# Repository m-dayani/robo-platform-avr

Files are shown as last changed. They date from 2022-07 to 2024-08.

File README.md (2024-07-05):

# ROBO Platform | AVR Controller

The AVR microcontroller board is a component of the [Robo Platform project](https://github.com/m-dayani/robo-platform), which provides general-purpose inputs and outputs for a cell phone controller. Both hardware schematics and software are available.

This project is based on the [Obdev V-USB Library](https://www.obdev.at/products/vusb/index.html).

## Hardware

The hardware was initially designed for the [ATMEL ATmega8](https://www.microchip.com/en-us/product/ATMEGA8) AVR microcontroller using the Cadsoft Eagle (now [Autodesk Eagle](https://www.autodesk.com/products/eagle/free-download)).
Schematics and PCB layouts are available for SMD and TH (Through hole) technologies.

## Software

Based on the V-USB library, the algorithm handles USB interactions with an Android device (the [Robo Platform Android App](https://github.com/m-dayani/robo-platform-android)) and produces the required signals and commands.

The program is written in the C programming language and developed, compiled, and tested in [ATMEL AVR Studio 6.1](https://www.microchip.com/en-us/tools-resources/archives/avr-sam-mcus).

## Usage

The instructions to use this project are the same as any other Obdev V-USB project:

- Prepare the development board
- Implement your logic, link the library, and compile
- Upload the .hex file to the microcontroller
- You should also install an appropriate driver to connect the board to a desktop computer. This step can be skipped for connections to Android devices (using an OTG cable, Android auto-detects the device).

You can learn more about it in [this step-by-step tutorial](https://codeandlife.com/2012/01/22/avr-attiny-usb-tutorial-part-1/).

_WARNING_: Be careful with fuse bits when flashing your microcontroller in Linux (using Makefile). It is recommended you do not use `program` or `fuse` targets with `make`. If you upload the wrong fuse bits, your device might not work again.

## Troubleshooting

In case the board does not respond to USB commands:

- Check the connections
- Make sure the program is compiled for the right microcontroller (e.g. Atmega32)
- Make sure the frequency is correct (12MHz) and fuse bits are programmed correctly

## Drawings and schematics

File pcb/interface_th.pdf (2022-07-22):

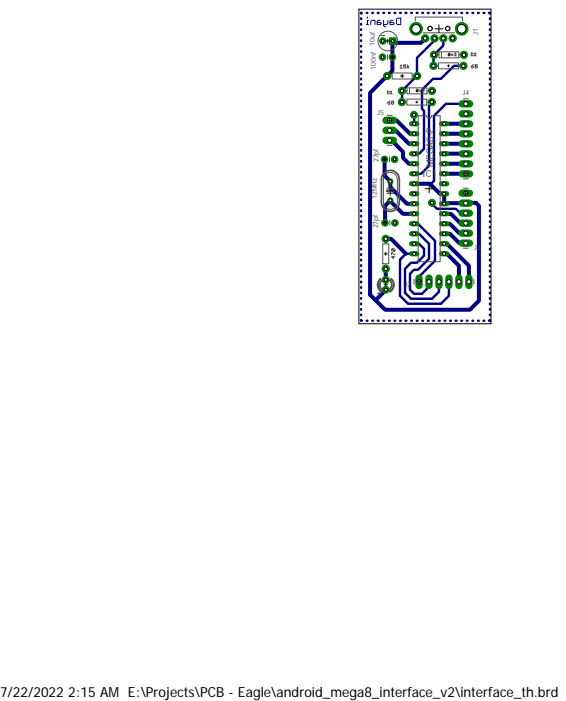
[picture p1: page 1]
MEGA8-P; 12MHz

7/22/2022 2:15 AM E:\Projects\PCB - Eagle\android_mega8_interface_v2\interface_th.brd

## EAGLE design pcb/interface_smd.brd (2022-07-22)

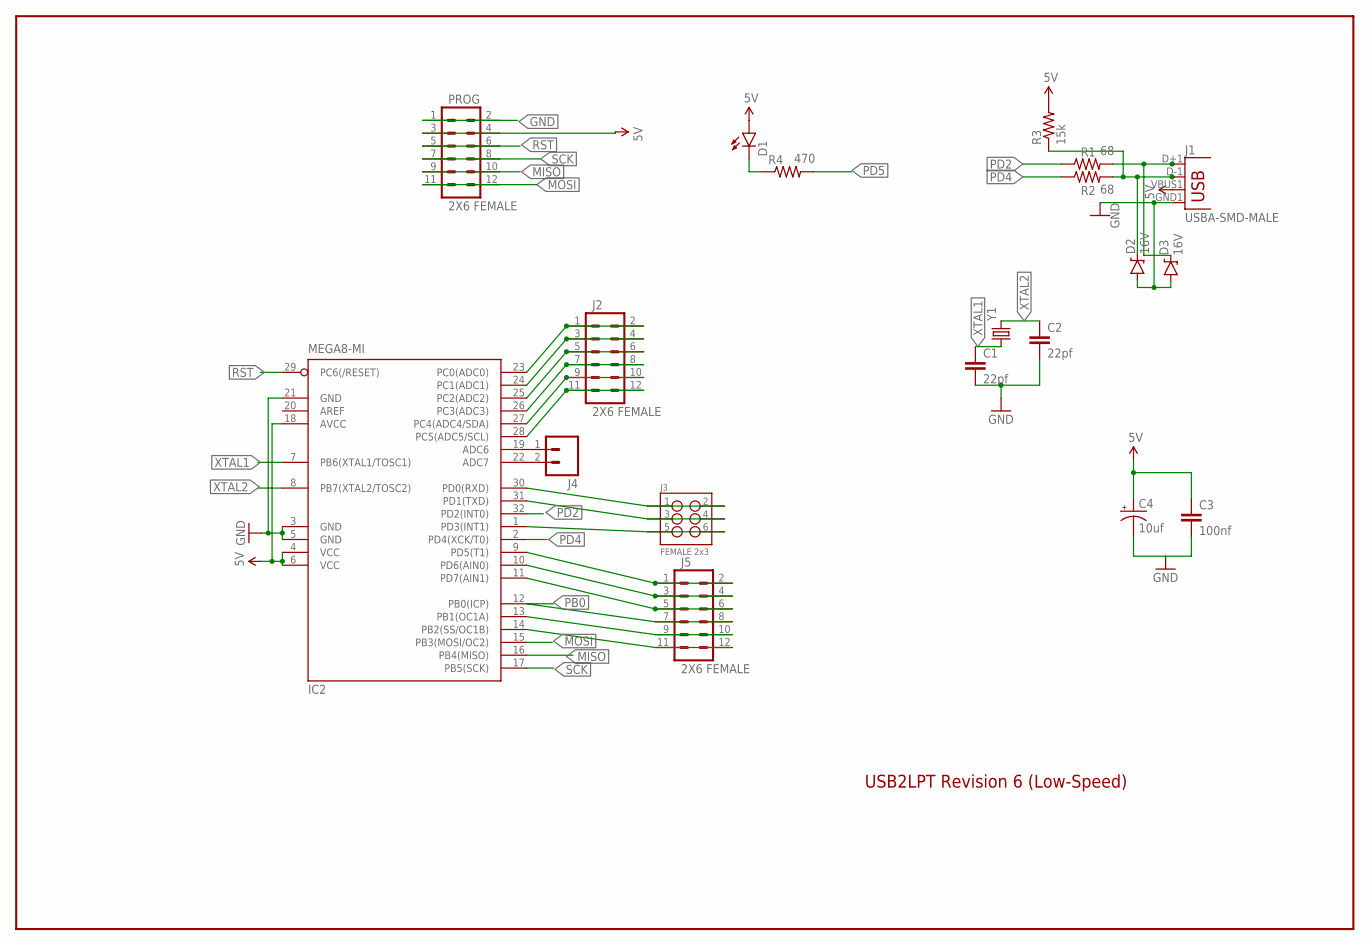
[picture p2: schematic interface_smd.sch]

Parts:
C1, C2: 22pf; 1206
C3: 100nf; 1206
C4: 10uf; EIA3216
D1: LED1206; LED-1206
D2, D3: 16V; SOD-123
IC2: MEGA8-MI; MLF32
J1: USBA-SMD-MALE; USB-A-SMT-MALE
J2, J5: 2X6 FEMALE; 2X6
J3: FEMALE 2x3; 2X3
J4: M02PTH; 1X02
PROG: 2X6 FEMALE; 2X6
R1, R2: 68; 1206
R3: 15k; 1206
R4: 470; 1206
Y1: CRYSTAL10.5X4.8; CRYSTAL-SMD-10.5X4.8-2PIN

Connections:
5V: C3.1, C4.A (+), D1.A, IC2.4 (VCC), IC2.6 (VCC), IC2.18 (AVCC), J1.VBUS1 (VBUS), PROG.3, PROG.4, R3.2
GND: C1.2, C2.2, C3.2, C4.C (-), D2.A, D3.A, IC2.3 (GND), IC2.5 (GND), IC2.21 (GND), J1.GND1 (GND), PROG.1, PROG.2
MISO: IC2.16 (PB4(MISO)), PROG.9, PROG.10
MOSI: IC2.15 (PB3(MOSI/OC2)), PROG.11, PROG.12
unnamed: D1.C, R4.1
unnamed: IC2.23 (PC0(ADC0)), J2.1, J2.2
unnamed: D3.C, J1.D+1 (D+), R1.2
unnamed: IC2.24 (PC1(ADC1)), J2.3, J2.4
unnamed: IC2.25 (PC2(ADC2)), J2.5, J2.6
unnamed: D2.C, J1.D-1 (D-), R2.2, R3.1
unnamed: IC2.26 (PC3(ADC3)), J2.7, J2.8
unnamed: IC2.27 (PC4(ADC4/SDA)), J2.9, J2.10
unnamed: IC2.28 (PC5(ADC5/SCL)), J2.11, J2.12
unnamed: IC2.19 (ADC6), J4.1
unnamed: IC2.22 (ADC7), J4.2
unnamed: IC2.30 (PD0(RXD)), J3.1, J3.2
unnamed: IC2.31 (PD1(TXD)), J3.3, J3.4
unnamed: IC2.1 (PD3(INT1)), J3.5, J3.6
unnamed: IC2.10 (PD6(AIN0)), J5.3, J5.4
unnamed: IC2.11 (PD7(AIN1)), J5.5, J5.6
unnamed: IC2.13 (PB1(OC1A)), J5.9, J5.10
unnamed: IC2.14 (PB2(SS/OC1B)), J5.11, J5.12
PB0: IC2.12 (PB0(ICP)), J5.7, J5.8
PD2: IC2.32 (PD2(INT0)), R1.1
PD4: IC2.2 (PD4(XCK/T0)), R2.1
PD5: IC2.9 (PD5(T1)), J5.1, J5.2, R4.2
RST: IC2.29 (PC6(/RESET)), PROG.5, PROG.6
SCK: IC2.17 (PB5(SCK)), PROG.7, PROG.8
XTAL1: C1.1, IC2.7 (PB6(XTAL1/TOSC1)), Y1.P$1 (1)
XTAL2: C2.1, IC2.8 (PB7(XTAL2/TOSC2)), Y1.P$2 (2)

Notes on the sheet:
USB2LPT Revision 6 (Low-Speed)

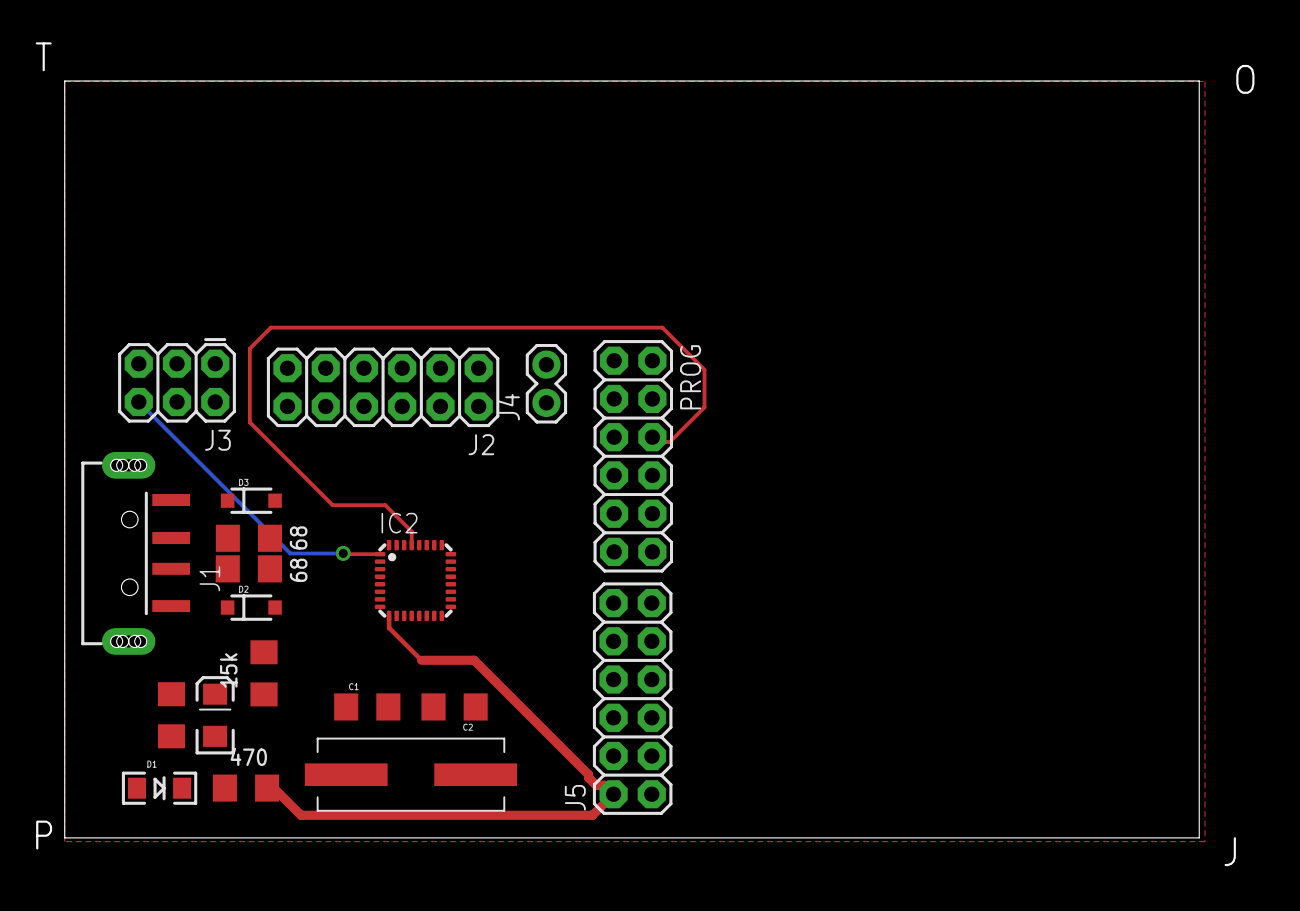
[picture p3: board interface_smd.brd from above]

Board: 2 copper layers, 75.4 x 50.3 mm, 19 parts (0 on the bottom side), 30 nets.

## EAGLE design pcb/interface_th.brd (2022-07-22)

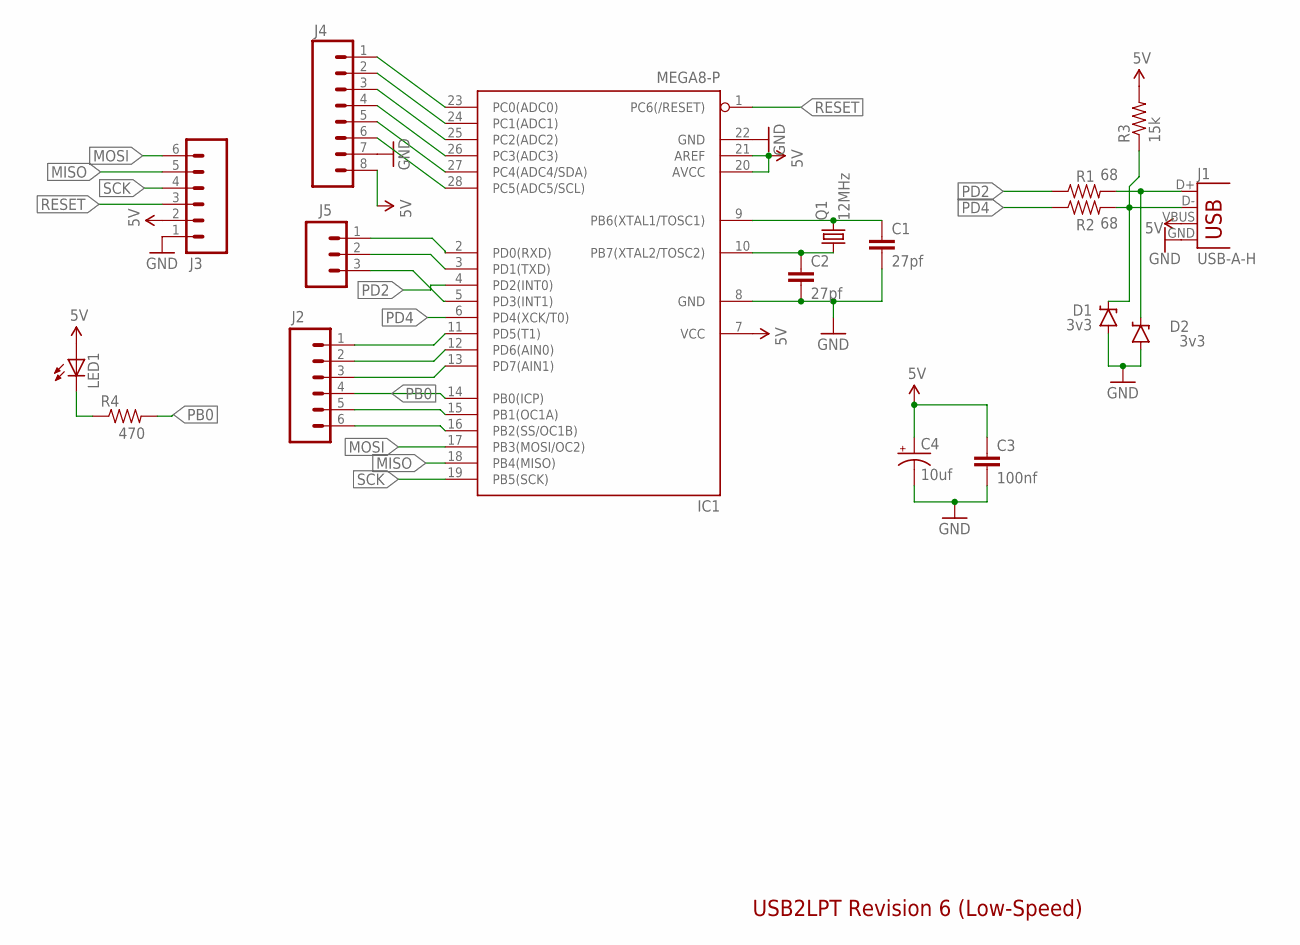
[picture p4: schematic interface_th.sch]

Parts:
C1, C2: 27pf; CAP-PTH-SMALL
C3: 100nf; CAP-PTH-SMALL
C4: 10uf; CPOL-RADIAL-10UF-25V
D1, D2: 3v3; DIODE-BZT52
IC1: MEGA8-P; DIL28-3
J1: USB-A-H
J2, J3: M06LONGPADS; 1X06_LONGPADS
J4: M08LONGPADS; 1X08_LONGPADS
J5: M03LONGPADS; 1X03_LONGPADS
LED1: LED3MM
Q1: 12MHz; HC49U-V
R1, R2: 68; AXIAL-0.3
R3: 15k; AXIAL-0.3
R4: 470; AXIAL-0.3

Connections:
5V: C3.1, C4.1 (+), IC1.7 (VCC), IC1.20 (AVCC), IC1.21 (AREF), J1.VBUS, J3.2, J4.8, LED1.A, R3.P$2 (2)
GND: C1.2, C2.2, C3.2, C4.2 (-), D1.A, D2.A, IC1.8 (GND), IC1.22 (GND), J1.GND, J3.1, J4.7
MISO: IC1.18 (PB4(MISO)), J3.5
MOSI: IC1.17 (PB3(MOSI/OC2)), J3.6
unnamed: LED1.K (C), R4.P$1 (1)
unnamed: IC1.11 (PD5(T1)), J2.1
unnamed: IC1.23 (PC0(ADC0)), J4.1
unnamed: C2.1, IC1.10 (PB7(XTAL2/TOSC2)), Q1.1
unnamed: C1.1, IC1.9 (PB6(XTAL1/TOSC1)), Q1.2
unnamed: D1.C, J1.D-, R2.P$2 (2), R3.P$1 (1)
unnamed: D2.C, J1.D+, R1.P$2 (2)
unnamed: IC1.24 (PC1(ADC1)), J4.2
unnamed: IC1.25 (PC2(ADC2)), J4.3
unnamed: IC1.26 (PC3(ADC3)), J4.4
unnamed: IC1.27 (PC4(ADC4/SDA)), J4.5
unnamed: IC1.28 (PC5(ADC5/SCL)), J4.6
unnamed: IC1.12 (PD6(AIN0)), J2.2
unnamed: IC1.13 (PD7(AIN1)), J2.3
unnamed: IC1.15 (PB1(OC1A)), J2.5
unnamed: IC1.16 (PB2(SS/OC1B)), J2.6
unnamed: IC1.2 (PD0(RXD)), J5.1
unnamed: IC1.3 (PD1(TXD)), J5.2
unnamed: IC1.5 (PD3(INT1)), J5.3
PB0: IC1.14 (PB0(ICP)), J2.4, R4.P$2 (2)
PD2: IC1.4 (PD2(INT0)), R1.P$1 (1)
PD4: IC1.6 (PD4(XCK/T0)), R2.P$1 (1)
RESET: IC1.1 (PC6(/RESET)), J3.3
SCK: IC1.19 (PB5(SCK)), J3.4

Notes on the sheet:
USB2LPT Revision 6 (Low-Speed)

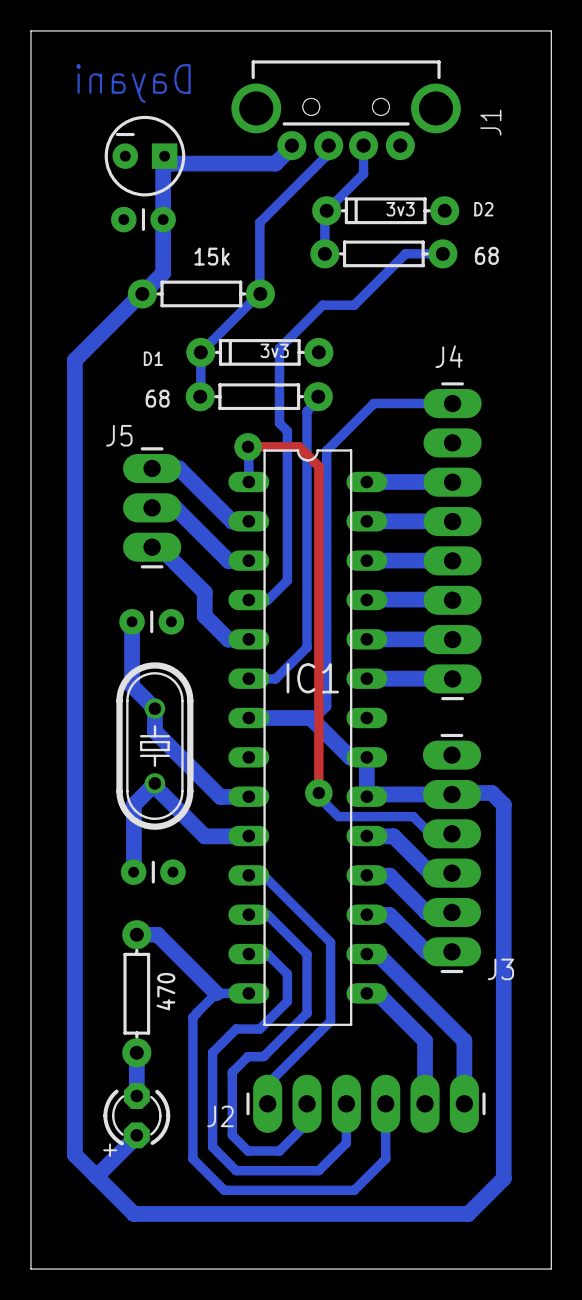
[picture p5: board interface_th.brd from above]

Board: 2 copper layers, 33.6 x 79.9 mm, 18 parts (0 on the bottom side), 28 nets.

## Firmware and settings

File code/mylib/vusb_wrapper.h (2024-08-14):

#pragma once

#ifndef ARDUINO
#include "../thirdparty/usbdrv/usbdrv.h"
#include "../thirdparty/usbdrv/oddebug.h"
#else
#include <Arduino.h>
#endif

#ifndef ARDUINO
#ifndef uchar
#define uchar unsigned char
#endif
#else
typedef unsigned char uchar;
#endif

#define LEN_USB_BUFF_IN 64
#define LEN_USB_BUFF_OUT 64

#define DEFAULT_TEST_IN_MESSAGE "in-code-9372"
#define DEFAULT_TEST_OUT_MESSAGE                                        \
    {                                                                   \
        'o', 'u', 't', '-', 'c', 'o', 'd', 'e', '-', '6', '3', '3', '4' \
    }
#define DEFAULT_TEST_OUT_MSG_LEN 13
#define DEFAULT_TEST_IN_MSG_LEN 12

enum UsbCommand
{
    CMD_BROADCAST,
    CMD_UPDATE_OUTPUT,
    CMD_GET_SENSOR_INFO,
    CMD_GET_CMD_RES,
    CMD_ADC_START,
    CMD_ADC_READ,
    CMD_ADC_STOP,
    CMD_RUN_TEST,
    CMD_TEST_LTC,
    CMD_TEST_TP,
    CMD_STR_MSG
} command_flag;

// USB input (read) buffer
extern uchar inputBuffer[LEN_USB_BUFF_IN];
// USB output (write) buffer
extern uchar outputBuffer[LEN_USB_BUFF_OUT];
// USB temp buffer (writing long messages)
extern uchar tempBuffer[LEN_USB_BUFF_OUT];
// Testing Note3 claim.
extern uchar stateBuffPos;
extern uchar lenDataCmd;
extern int tpCount;

#ifdef __cplusplus
extern "C"
{
#endif

    void clearBuffer(uchar *buff, uchar offset, uchar len);

    void insertBuffer(uchar *lBuff, uchar lBuffLen, uchar *rBuff, uchar rBuffLen, uchar offset);

    void readBuffer(uchar *lBuff, uchar lBuffLen, uchar *rBuff, uchar rBuffLen, uchar offset);

    uchar decodeData(uchar *input, uchar lenInput, uchar *output, uchar lenOutput, uchar *state);

    void encodeData(uchar *input, uchar lenInput, uchar *output, uchar lenOutput, uchar state);

    uchar cmdCompare(char *lCmd, uchar *rCmd, uchar len);

    void setResponseOK(uchar state);

    uchar cmp_code(char *code1, char lenCode1, uchar *code2, char lenCode2);

    void setLatencyCode(uchar state);

    uchar processTpBuff(uchar *buff, uchar len);

    void cleanStatesCmdRes(void);

#ifdef __cplusplus
}
#endif

/* ======================================== USB Section ======================================== */

/* ----------------------------------- HID Report Descriptors ---------------------------------- */

/* ------------------------------------- Helper functions -------------------------------------- */

void usbRe_enumerate(void);

void runTestSequence(void);

uchar processDataCommand(uchar lenCmd, uchar state);

void processCommand(void);

// Interrupt part of USB library.
#ifdef USB_CFG_HAVE_INTRIN_ENDPOINT
void usbInterrupt(void);
#endif

/* --------------------------------------- Setup function -------------------------------------- */

#ifndef ARDUINO
USB_PUBLIC uchar usbFunctionSetup(uchar data[8]);
#endif

/* ------------------------------------ Read/Write functions ----------------------------------- */

#if USB_CFG_IMPLEMENT_FN_WRITE
// Regular 8Bytes write.
// For at most 8 Bytes of data, writes are much simpler
// void receive8ByteDt(uchar *data, uchar len);

// Use this for large buffer writes (> 8 Bytes).
// void receiveBuffer(uchar *data, uchar len);

char receiveBuffer1(uchar *data, uchar len);

/*
    For long data in, if usbFunctionSetup returns USB_NO_MSG, this function
    is automatically called.
    In this case, outputBuffer is updated for both test/non-test commands
*/
#ifndef ARDUINO
USB_PUBLIC uchar usbFunctionWrite(uchar *data, uchar len);
#endif
#endif

#if USB_CFG_IMPLEMENT_FN_READ
/*
 * usbFunctionRead() is called when the host requests a chunk of data from
 * the device. For more information, see the documentation in usbdrv/usbdrv.h.
 */
#ifndef ARDUINO
USB_PUBLIC uchar usbFunctionRead(uchar *data, uchar len);
#endif
#endif

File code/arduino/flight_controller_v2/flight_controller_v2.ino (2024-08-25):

#include <time.h> 
#include <math.h>
#include <Servo.h>

#define PWM_A 3
#define PWM_B 9
#define PWM_C 10
#define PWM_D 11


enum UsbCommand {
  CMD_BROADCAST,
  CMD_UPDATE_OUTPUT,
  CMD_GET_SENSOR_INFO,
  CMD_GET_CMD_RES,
  CMD_ADC_START,
  CMD_ADC_READ,
  CMD_ADC_STOP,
  CMD_RUN_TEST,
  CMD_TEST_LTC,
  CMD_TEST_TP,
  CMD_STR_MSG
};


const int buffLen = 64;
unsigned char inputBuff[buffLen];
unsigned char outputBuff[buffLen];

const String inCode = "in-code-9372";
const char LenInCode = 12;
const String outCode = "out-code-6334";
const char LenOutCode = 13;
bool test_done = false;

Servo servo_a, servo_b, servo_c, servo_d;
bool pwm_mode = false;

unsigned char state_a = 0, state_b = 0, state_c = 0, state_d = 0;
unsigned char max_cnt = 255;
// unsigned char ctrl_state = 0x00;

bool led_state = false;


void my_serial_read(int& len, unsigned char& code, unsigned char* buffer, int max_buff) {

  unsigned char cmd[2];
  Serial.readBytes(cmd, 2);
  len = cmd[0];
  code = cmd[1];
  if (code == UsbCommand::CMD_TEST_TP && buffLen > 64) {
    len = len * 64 - 2;
  }
  Serial.readBytes(buffer, len);
}

void my_serial_write(int len, unsigned char code, unsigned char* buffer, int max_buff) {

  if (len > max_buff) {
    return;
  }
  Serial.write(len);
  Serial.write(code);
  for (int i = 0; i < len; i++) {
    Serial.write(buffer[i]);
  }
}

bool check_test(int len, unsigned char* buffer) {

  if (len != LenInCode) {
    return false;
  }
  for (int i = 0; i < len; i++) {
    if (buffer[i] != inCode[i]) {
      return false;
    }
  }
  test_done = true;
  return true;
}

void send_test_response() {
  my_serial_write(LenOutCode, 0, outCode.c_str(), LenOutCode);
}

void toggle_led(void) {

  if (!led_state) {
    digitalWrite(LED_BUILTIN, HIGH);
    led_state = true;
  }
  else {
    digitalWrite(LED_BUILTIN, LOW);
    led_state = false;
  }
}

void test_analog() {
  int sensorValue = analogRead(A0);
  int outputValue = map(sensorValue, 0, 1023, 0, 255);
  analogWrite(PWM_A, outputValue);
  analogWrite(PWM_B, outputValue);
  analogWrite(PWM_C, outputValue);
  analogWrite(PWM_D, outputValue);
}

void update_analog() {

  // unsigned char value = (unsigned char) (((float) cnt_a / (float) max_cnt) * 255.0);
  analogWrite(PWM_A, map(state_a, 0, max_cnt, 0, 255));
  analogWrite(PWM_B, map(state_b, 0, max_cnt, 0, 255));
  analogWrite(PWM_C, map(state_c, 0, max_cnt, 0, 255));
  analogWrite(PWM_D, map(state_d, 0, max_cnt, 0, 255));
}

void update_pwm() {

  servo_a.write(map(state_a, 0, max_cnt, 0, 180));
  servo_b.write(map(state_b, 0, max_cnt, 0, 180));
  servo_c.write(map(state_c, 0, max_cnt, 0, 180));
  servo_d.write(map(state_d, 0, max_cnt, 0, 180));
}

void update_states(unsigned char* buffer, unsigned char len) {

    if (len < 4) {
      return;
    }
    state_a = buffer[0];
    state_b = buffer[1];
    state_c = buffer[2];
    state_d = buffer[3];
}

void update_output_with_states(void) {
  outputBuff[0] = state_a;
  outputBuff[1] = state_b;
  outputBuff[2] = state_c;
  outputBuff[3] = state_d;
}

void setup_pwm(void) {
  servo_a.attach(PWM_A);
  servo_b.attach(PWM_B);
  servo_c.attach(PWM_C);
  servo_d.attach(PWM_D);
}


void setup() {

  // Serial.begin(9600);
  Serial.begin(115200);
  Serial.setTimeout(100);

  pinMode(LED_BUILTIN, OUTPUT);

  if (pwm_mode) {
    setup_pwm();
  }
}

void loop() {

  // Syncronization
  // while(!Serial.available()) {}
  
  if (Serial.available() > 0) {
    
    int len = 0;
    unsigned char code = 0;
    my_serial_read(len, code, inputBuff, buffLen);

    if (check_test(len, inputBuff)) {
      send_test_response();
    }
    else if (code == UsbCommand::CMD_UPDATE_OUTPUT) {
      // Directional commands
      // update current states
      update_states(inputBuff, len);
      // send back last state -> maybe this is redundant??
      update_output_with_states();
      my_serial_write(len, UsbCommand::CMD_GET_CMD_RES, outputBuff, buffLen);
    }
    else {
      my_serial_write(len, code, inputBuff, buffLen);
    }
  }

  if (pwm_mode) {
    update_pwm();
  }
  else {
    update_analog();
    // test_analog();
  }
  // delay(5);
}

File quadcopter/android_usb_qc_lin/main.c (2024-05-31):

/* Name:	android_usb_mega8.c
 * Project:	USB Interface to android device,
 *			For robotic purposes, No HID Implementation
 * Author:	M. Dayani
 * Created:	02/05/2024
 *
 * Quadcopter Controller (Compiled on Linux)
 */

#define __DELAY_BACKWARD_COMPATIBLE__
#include <avr/io.h>
#include <avr/interrupt.h>
#include <avr/eeprom.h>
#include <avr/pgmspace.h>
#include <avr/wdt.h>
#include <util/delay.h>

#include "usbdrv.h"
#include "oddebug.h"

#define max(a, b) \
	({ __typeof__ (a) _a = (a); \
	   __typeof__ (b) _b = (b); \
	 _a > _b ? _a : _b; })

#define min(a, b) \
	({ __typeof__ (a) _a = (a); \
	   __typeof__ (b) _b = (b); \
	 _a < _b ? _a : _b; })

#define LED_BIT 7
#define LED_DDR DDRB
#define LED_PORT PORTB

#define OUT_CTRL_DDR DDRB
#define OUT_CTRL_PORT PORTB

#define LEN_USB_BUFF_IN 64
#define LEN_USB_BUFF_OUT 64
#define LEN_ADC_BUFF 16

#define DEFAULT_TEST_IN_MESSAGE "in-code-9372"
#define DEFAULT_TEST_OUT_MESSAGE                                        \
	{                                                                   \
		'o', 'u', 't', '-', 'c', 'o', 'd', 'e', '-', '6', '3', '3', '4' \
	}
#define DEFAULT_TEST_OUT_MSG_LEN 13
#define DEFAULT_OUT_CTRL_INIT_VAL 0x00

#define SENSORS_ADC_AVAILABLE 1
#define SENSORS_EXT_AVAILABLE 0
#define ROBO_CTRL_AVAILABLE 1

#define ADC_N_CHANNELS 1
#define ADC_PRESCALER 128
#define ADC_SRC_FREQ_MHZ 12
#define ADC_RESOLUTION_BITS 10

enum UsbCommand
{
	CMD_BROADCAST,
	CMD_UPDATE_OUTPUT,
	CMD_GET_SENSOR_INFO,
	CMD_GET_CMD_RES,
	CMD_ADC_START,
	CMD_ADC_READ,
	CMD_ADC_STOP,
	CMD_RUN_TEST
} command_flag;

static uchar ledStat = 0;

static uchar currChAdc = 0;
static uchar adcStartedFlag = 0;

// ACD results buffer (8 2-byte channels)
static uchar adcBuffer[LEN_ADC_BUFF];

// USB input (read) buffer
static uchar inputBuffer[LEN_USB_BUFF_IN];
// USB output (write) buffer
static uchar outputBuffer[LEN_USB_BUFF_OUT];
// Testing Note3 claim.
static uchar stateBuffPos = 0;

uchar ctrl_state = 0x00;

// A 50 Hz PWM pulse (20000 us)
// For a real servo or ESC:
// cnt_offset = 1415, max_cnt = 2815, max_cnt_cycle = 117
// For LED test (dimmer):
// cnt_offset = 0, max_cnt = 200, max_cnt_cycle = 200 (or 180)
const unsigned short max_cnt_cycle = 117;
unsigned short cnt_cycle = 0;

const unsigned short max_cnt = 2815;
const unsigned short cnt_offset = 1415;
const double max_time = 10000.0;
const unsigned short max_time_int = 10000;

// 4 Channels for PWM Generation (to ESC)
// A: PB0, B: PB1, C: PB2, D: PB3
// Dynamic counters (changed in every loop)
unsigned long cnt_a = 0, cnt_b = 0, cnt_c = 0, cnt_d = 0;
// Max count determining duty cycle (changed with commands)
unsigned int cap_a = 0, cap_b = 0, cap_c = 0, cap_d = 0;
// Change max count based on the time of command
unsigned long t_a = 0, t_b = 0, t_c = 0, t_d = 0;

/* =================================== Function Declarations =================================== */

/* ===================================== Config. & Helpers ===================================== */

void mainInit()
{
	// LED
	LED_DDR |= 1 << LED_BIT;
	// set control port as output
	OUT_CTRL_DDR = 0xFF;
	// Enable motor driver: Enable wire attached to PB2
	OUT_CTRL_PORT = 0x00;
}

static void setLED(uchar newValue)
{
	ledStat = newValue;
	if (ledStat)
	{
		LED_PORT |= 1 << LED_BIT; // LED on
	}
	else
	{
		LED_PORT &= ~(1 << LED_BIT); // LED off
	}
}

void toggleLED(void)
{
	if (ledStat)
	{
		setLED(0);
	}
	else
	{
		setLED(1);
	}
}

void clearBuffer(uchar *buff, uchar offset, uchar len)
{
	for (uchar i = offset, totalLen = offset + len; i < totalLen; i++)
	{
		buff[i] = 0;
	}
}

void insertBuffer(uchar *lBuff, uchar lBuffLen, uchar *rBuff, uchar rBuffLen, uchar offset)
{
	for (uchar i = offset, totalBuffLen = offset + rBuffLen; i < lBuffLen && i < totalBuffLen; i++)
	{
		lBuff[i] = rBuff[i - offset];
	}
}

void readBuffer(uchar *lBuff, uchar lBuffLen, uchar *rBuff, uchar rBuffLen, uchar offset)
{
	for (uchar i = offset, totalBuffLen = offset + rBuffLen; i < lBuffLen && i < totalBuffLen; i++)
	{
		lBuff[i - offset] = rBuff[i];
	}
}

uchar decodeData(uchar *input, uchar lenInput, uchar *output, uchar lenOutput, uchar *state)
{
	if (lenInput < 2)
	{
		return 0;
	}

	uchar lenData = input[0];
	*state = input[1];

	lenOutput = min(lenData, lenOutput);
	readBuffer(output, lenOutput, input, lenInput, 2);

	return lenOutput;
}

void encodeData(uchar *input, uchar lenInput, uchar *output, uchar lenOutput, uchar state)
{
	if (lenOutput < 2)
	{
		return;
	}

	output[0] = lenInput;
	output[1] = state; // command or data

	insertBuffer(output, lenOutput, input, lenInput, 2);
}

uchar cmdCompare(char *lCmd, uchar *rCmd, uchar len)
{
	uchar lCmdLen = sizeof(lCmd);

	for (uchar i = 0; i < len && i < lCmdLen; i++)
	{
		if (lCmd[i] != rCmd[i])
			return 0;
	}

	return 1;
}

void setResponseOK(uchar state)
{
	clearBuffer(inputBuffer, 0, LEN_USB_BUFF_IN);
	uchar buff[] = {state};
	encodeData(buff, 1, inputBuffer, LEN_USB_BUFF_IN, 0);
}

/* ====================================== Sensor Functions ===================================== */

/* --------------------------------------- ADC Functions --------------------------------------- */

static uchar isAdcStarted()
{
	return adcStartedFlag;
}

static void adcStart()
{
	adcStartedFlag = 1;
	ADCSRA |= (1 << ADSC);
}

static void adcStop()
{
	adcStartedFlag = 0;
	ADCSRA &= ~(1 << ADSC);
}

static void adcInit(void)
{
	// channel: ADC0, vRef = AVCC (5v), right adjust (for 10 bit res)
	ADMUX |= (1 << REFS0); //| (1 << ADLAR)
	// Pre-scaler: 128
	ADCSRA |= (SENSORS_ADC_AVAILABLE << ADEN) | (1 << ADPS2) | (1 << ADPS1) | (1 << ADPS0); //| (1 << ADATE) | (1 << ADIE)
																							// no free running mode, no high speed mode
																							// SFIOR |= ;
}

static void adcPoll(uchar channel)
{
	// conversion complete?
	if (isAdcStarted() && !(ADCSRA & (1 << ADSC)))
	{

		uchar adcValues[2];
		adcValues[0] = ADCL;
		adcValues[1] = ADCH;

		insertBuffer(adcBuffer, LEN_ADC_BUFF, adcValues, 2, 2 * channel);

		// for faster response, fill input buffer here
		// WARNING: with this, we cannot send any other commands except usb read commands
		// encodeData(adcBuffer, 2 * ADC_N_CHANNELS, inputBuffer, LEN_USB_BUFF_IN, 0);

		// start next conversion *
		ADCSRA |= (1 << ADSC);
	}
}

/* ------------------------------------- External Sensors -------------------------------------- */

/* ---------------------------------------- Management ----------------------------------------- */
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

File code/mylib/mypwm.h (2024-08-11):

#pragma once

#ifndef ARDUINO
#include <avr/io.h>
#include <avr/interrupt.h>
#else
#include <Arduino.h>
#endif

#ifndef ARDUINO
#ifndef uchar
#define uchar unsigned char
#endif
#else
typedef unsigned char uchar;
#endif

// A 50 Hz PWM pulse (20000 us)
// For a real servo or ESC:
// cnt_offset = 1415, max_cnt = 2815, max_cnt_cycle = 117
// For LED test (dimmer):
// cnt_offset = 0, max_cnt = 200, max_cnt_cycle = 200 (or 180)
extern unsigned short max_cnt_cycle;
extern unsigned short cnt_cycle;

extern unsigned short max_cnt;
extern unsigned short cnt_offset;
extern double max_time;
extern unsigned short max_time_int;

// 4 Channels for PWM Generation (to ESC)
// A: PB0, B: PB1, C: PB2, D: PB3
// Dynamic counters (changed in every loop)
extern unsigned long cnt_a, cnt_b, cnt_c, cnt_d;
// Max count determining duty cycle (changed with commands)
extern unsigned int cap_a, cap_b, cap_c, cap_d;
// Change max count based on the time of command
extern unsigned long t_a, t_b, t_c, t_d;

extern char state_a, state_b, state_c, state_d;
extern int n_cycle;

/* ==================================== Signal Gen (timer) ======================================== */

#ifdef __cplusplus
extern "C" {
#endif

void capUpdate(unsigned int *cap, const unsigned long t);

void capUpdateAll(void);

void timeCtrlUpdate(unsigned long *t, const uchar nb_p, const uchar nb_n, const uchar nsh_p, const uchar nsh_n);

void timeCtrlUpdateAll(void);

void pwmUpdate(const unsigned long cnt, const unsigned int cap, const uchar p_val);

void pwmUpdateAll(void);

void countUpdate(void);

void cycleUpdate(void);

#ifndef ARDUINO
void timerInit(void);
#endif


void set_timer(void);

char update_state(const uchar mask, const uchar n_bit);

void update_states(void);

void update_cnt(unsigned long* cnt, const char state);

#ifdef __cplusplus
}
#endif

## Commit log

2022-10-03 added ADC and linux support
2023-10-20 updated all files
    [interface_smd.brd, interface_smd.sch, interface_th.brd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]
2024-05-31 completed quadcopter program, added arduino support for QC
2024-06-02 reorganized to support cmake generation
    [interface_smd.brd, interface_smd.sch, interface_th.brd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]
2024-06-21 modified Arduino's flight controller
2024-08-14 finished comm test, corrected flight controller
    [flight_controller.ino, rp_serial_test.ino, vusb_wrapper.c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]
2024-08-25 added a better Arduino flight controller (flight_controller_v2)

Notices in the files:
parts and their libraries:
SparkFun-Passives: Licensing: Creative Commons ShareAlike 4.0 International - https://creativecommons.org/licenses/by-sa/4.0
